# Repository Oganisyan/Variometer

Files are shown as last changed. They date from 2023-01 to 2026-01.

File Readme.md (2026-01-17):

# Paragliding Variometer on Basis of BikePilot2+ or Falk Tiger evo/geo/pro.
| AutoRunCE XCSoar | AutoRunCE Main Dialog | AutoRunCE Vario Settings |
|---|---|---|
|[](https://youtube.com/shorts/pAdE8dn8gpc)|[](https://youtube.com/shorts/2ggxs6w_VHQ)|[](https://youtube.com/shorts/l3dTKEIAxWs)|
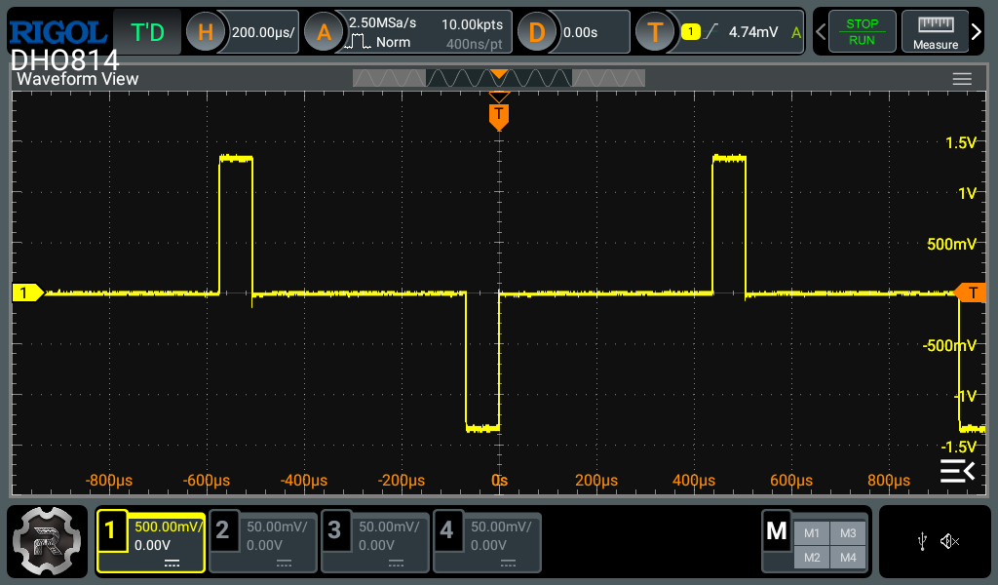
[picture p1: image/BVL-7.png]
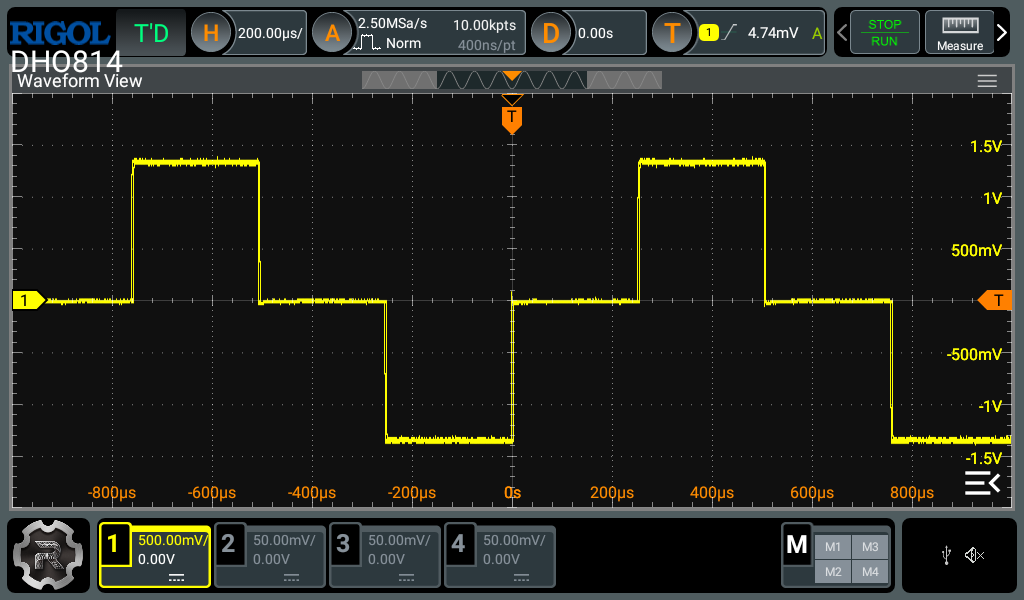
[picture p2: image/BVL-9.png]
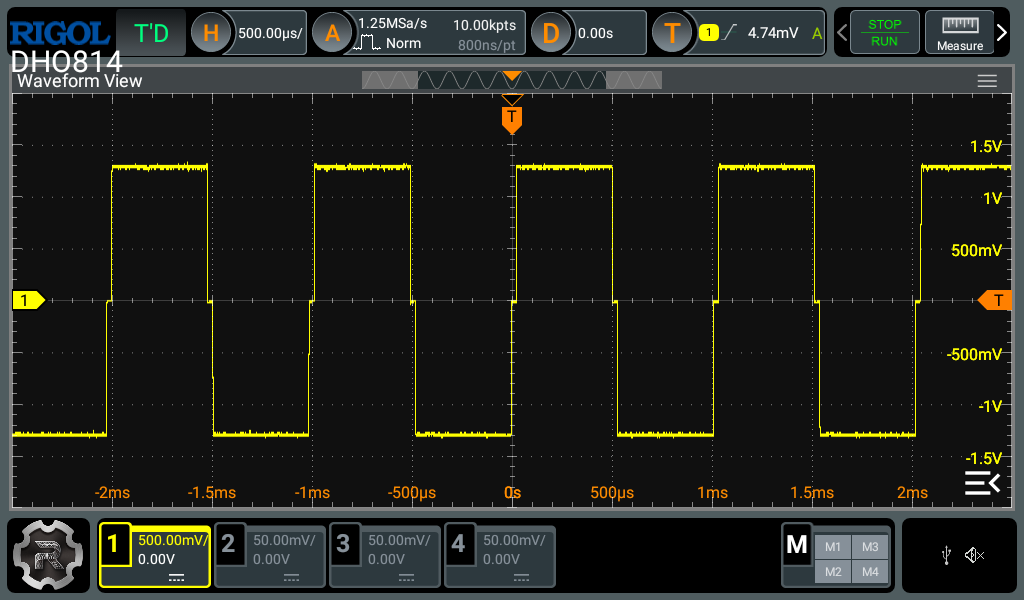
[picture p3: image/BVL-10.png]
| $BVL 7*|$BVL 9*|$BVL 10*|

## Build Step 1
build serial variometer and upload firmware
| | |
|---|---|
|Build informations |[./ATMega328P-AU/Readme.md](./ATMega328P-AU/Readme.md) |
|Firmware with bootloader |[./Firmware/SerialVariometer.with_bootloader.hex](./Firmware/SerialVariometer.with_bootloader.hex) |
|Firmware without bootloader  |[./Firmware/SerialVariometer.hex](./Firmware/SerialVariometer.hex) |

## Build Step 2
Open the BikePilot2+ and Install Serilal Variometer.
|                 Assembly                     |
|----------------------------------------------|
|                 |

## Build Step 3
Prepare the USB stick and insert the device (BikePilot2+).
|                                                                                        |
|----------------------------------------------------------------------------------------|
|copy [./Firmware/AutoRunCE.exe](./Firmware/AutoRunCE.exe) into root folder from USB stick |
|copy [./Firmware/AutoRunCE.ini](./Firmware/AutoRunCE.ini) into root folder from USB stick |
|copy [./Firmware/XCSoar.exe](./Firmware/XCSoar.exe) or www.xcsoar.org/Downloads into XCSoarData folder from USB stick |

| | |
|---|---|
|First  NMEA port / GPS signal|XCSoar gets GPS signal from COM0: (Bikepilot internal GPS).|
|Second NMEA port / pressure |AutoRunCE blocks serial variometer port (COM4 ) and forwards it to XCSoar via UDP broadcast on port 8882, BlueFly protocol should be used here.|

## done

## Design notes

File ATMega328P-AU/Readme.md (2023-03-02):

# Serial commands for variometer.
| Descripton | command line | value type |  value min | value max |
|---|---|---|---|---|
| set volume level | $BVL VALUE* |  INTEGER | 0 - OFF | 9 - max value |
| set lift threshold | $BUP VALUE* |  INTEGER | 0 - 0 m/s | 400 - 4 m/s |
| set sink threshold | $BDW VALUE* |  INTEGER | 0 - 0 m/s | 400 - 4 m/s |
| lift/sink simulation  | $SIM VALUE* |  INTEGER | -800 - 8m/s sink | 800 - 8m/s lift |
| reboot | $RST VALUE* |  INTEGER | 0 - reboot now | x - reboot in x seconds| 

# First step create serial variometer.

Before ATMega328P chip is soldered it is very important to upload bootloader for 8MHz internal crystal through SPI interface.
The firmware can be uploaded with the serial interface, but not the bootloader.

| | |
|---|---|
|Serial Vario for BikePilot2  | |
|Public folder for Production |https://aisler.net/p/OTGDHGCV |
|Fritzing Project & PCB files |[./pcb](./pcb) |
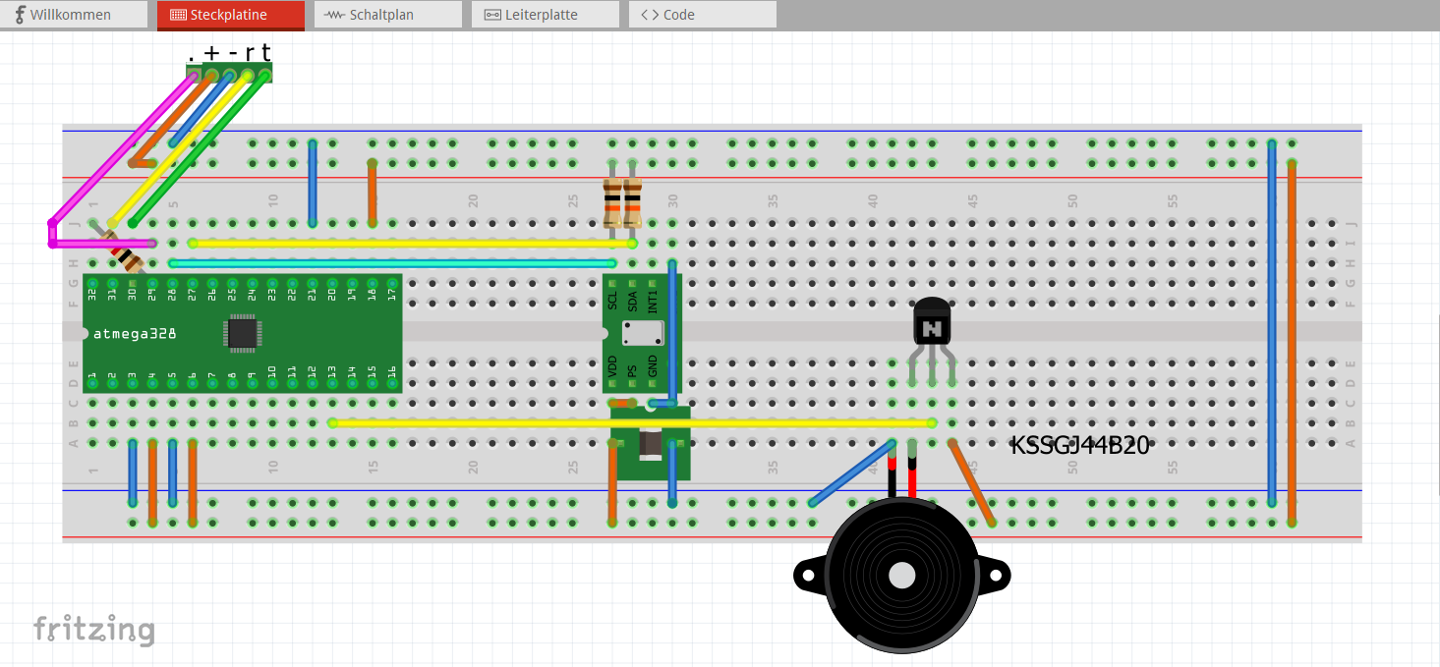
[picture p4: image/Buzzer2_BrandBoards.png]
|Breakout boards | |
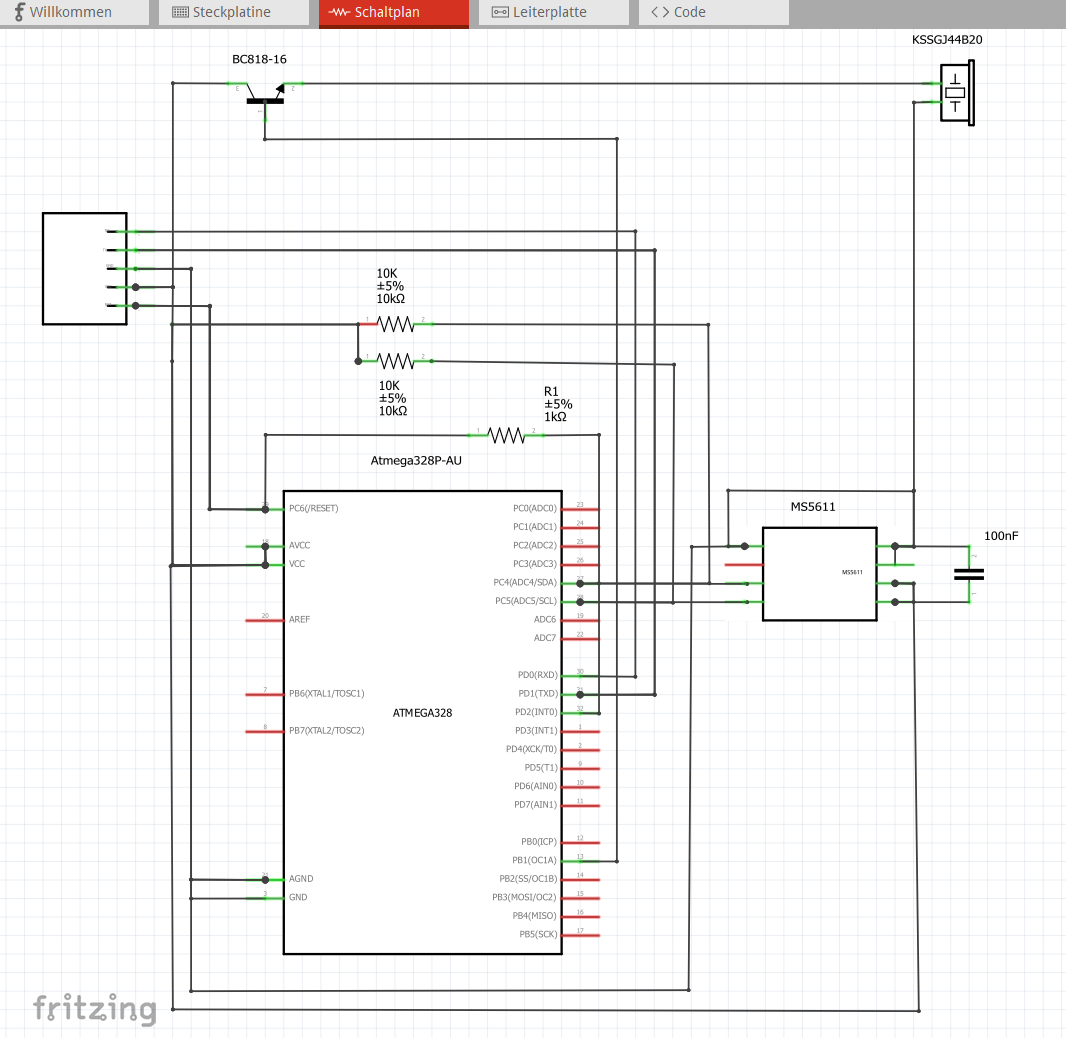
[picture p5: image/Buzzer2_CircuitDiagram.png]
|Circuit diagram ||

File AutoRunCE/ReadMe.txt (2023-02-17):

================================================================================
    MICROSOFT FOUNDATION CLASS-BIBLIOTHEK: AutoRunCE-Projektübersicht
===============================================================================

Der Anwendungs-Assistent hat diese AutoRunCE-Anwendung für Sie 
erstellt. Diese Anwendung zeigt nicht nur die Grundlagen der Verwendung von 
Microsoft Foundation Classes, sondern dient auch als Ausgangspunkt für das 
Schreiben Ihrer Anwendung.

Diese Datei enthält eine Zusammenfassung dessen, was Sie in jeder der Dateien
finden, aus denen Ihre AutoRunCE–Anwendung besteht.

AutoRunCE.vcproj
    Dies ist die Hauptprojektdatei für VC++-Projekte, die mithilfe eines 
    Anwendungs-Assistenten erstellt werden. 
    Sie enthält Informationen über die Version von Visual C++, in der die Datei 
    erzeugt wurde, sowie Informationen über die Plattformen, Konfigurationen und 
    Projektfunktionen, die mit dem Anwendungs-Assistenten ausgewählt wurden.

AutoRunCE.h
    Dies ist die Hauptheaderdatei für die Anwendung. Sie enthält weitere
    projektspezifische Header und deklariert die CAutoRunCEApp-
    Anwendungsklasse.

AutoRunCE.cpp
    Dies ist die Hauptquelldatei der Anwendung, die die CAutoRunCEApp-
    Anwendungsklasse enthält.

AutoRunCE.rc
    Dies ist die Hauptressourcendatei des Projekts, die alle Microsoft Windows-
    Ressourcen auflistet, die das Projekt verwendet. Sie enthält die Symbole, 
    Bitmaps und Cursor, die im Unterverzeichnis "RES" gespeichert werden. Diese 
    Datei kann direkt in Microsoft Visual C++ bearbeitet werden. Ihre 
    Projektressourcen befinden sich in 1031.
    Wenn die RC-Datei beibehalten wird, werden die Definitionen im 
    Datenabschnitt als Hexadezimalversion des numerischen Wertes, für den sie 
    definiert sind, gespeichert, und nicht als der angezeigte Name der 
    Definition.

res\AutoRunCE.rc2
    Diese Datei enthält Ressourcen, die nicht von Microsoft Visual C++
    bearbeitet werden. Sie sollten alle Ressourcen, die nicht mit dem
    Ressourcen-Editor bearbeitet werden können, in dieser Datei platzieren.

res\AutoRunCE.ico
    Dies ist eine Symboldatei, die als Symbol der Anwendung verwendet wird. 
    Dieses Symbol ist in der Hauptressourcendatei enthalten.

/////////////////////////////////////////////////////////////////////////////

Der Anwendungs-Assistent erstellt eine Dialogfeldklasse:

AutoRunCEDlg.h, AutoRunCEDlg.cpp – das Dialogfeld
    Diese Dateien enthalten Ihre CAutoRunCEDlg–Klasse. Diese Klasse 
    bestimmt das Verhalten des Hauptdialogfelds Ihrer Anwendung. Die Vorlage des 
    Dialogfelds befindet sich in der Hauptressourcendatei, die in Microsoft 
    Visual C++ bearbeitet werden kann.

/////////////////////////////////////////////////////////////////////////////

Weitere Standarddateien:

StdAfx.h, StdAfx.cpp
    Diese Dateien werden verwendet, um eine vorkompilierte Headerdatei
    (PCH-Datei) mit dem Namen "AutoRunCE.pch2 und eine 
    vorkompilierte Typendatei mit dem Namen "StdAfx.obj" zu erstellen.

Resource.h
    Dies ist die Standardheaderdatei, die neue Ressourcen-IDs definiert.
    Microsoft Visual C++ liest und aktualisiert diese Datei.

/////////////////////////////////////////////////////////////////////////////

Weitere Hinweise:

Der Anwendungs-Assistent verwendet "TODO:, um auf Teile des Quellcodes
hinzuweisen, die Sie hinzufügen oder anpassen sollten.

Wenn Ihre Anwendung MFC in einer freigegebenen DLL verwendet und Ihre Anwendung
in einer anderen als der aktuellen Sprache des Betriebssystems vorliegt,
müssen Sie die entsprechenden lokalisierten Ressourcen "MFC90XXX.DLL" in Ihr
Anwendungsverzeichnis kopieren ("XXX" steht für die Sprachabkürzung. "MFC90DEU.DLL" enthält beispielsweise ins Deutsche übersetzte Ressourcen.) Wenn Sie dies nicht tun, bleiben einige der Benutzeroberflächenelemente Ihrer Anwendung in der Sprache des Betriebssystems.

/////////////////////////////////////////////////////////////////////////////

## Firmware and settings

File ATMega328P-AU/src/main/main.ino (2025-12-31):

#include <Arduino.h>
#include <Wire.h>
#include "Tone.h"
#include "Reader.h"
#include "Config.h"
#include <avr/wdt.h>

#include "MS5611.h"

// PIN I2C_SCL              A4 // PC4
// PIN I2C_SDA              A5 // PC5
#define BEEP_PIN            A2 // PC2
//#define RX_PIN            10 // PB2 
//#define TX_PIN            9  // PB1
#define RESET_PIN           2

#define EEPROM_ADDRESE_VALUE  0



float   toneFreqLowpass, pressure, lowpassFast, lowpassSlow, upBarrier, upMax, dwBarrier, dwMax, sim = 0.F, P1, P2, P3, P4;

int16_t ddsAcc;

MS5611 ms5611(Wire);
Tone   myTone;
Reader reader(Serial);
Config config;



void sensitivity (int sensi) {
  sensi =  constrain(sensi, SEN_MIN, SEN_MAX);
  P1 = (5.F+ sensi)/50;
  P2 = P1 / 2;
  P3 = 500.F * P1;
  P4 = P3 * P1;
  config.setSensi(sensi);
}

void printBr() {
  Serial.print("UpBr: ");
  Serial.print(upBarrier);
  Serial.print(" UpMax: ");
  Serial.print(upMax);
  Serial.print(" DwBr: ");
  Serial.print(dwBarrier);
  Serial.print(" DwMax ");
  Serial.println(dwMax);
}

// up barrier m/s*100
void setUpBarrier(int up_100) {
  up_100 = constrain(up_100, UP_MIN, UP_MAX);
  upBarrier=max(25.F, 1.6F*up_100);
  upMax=upBarrier+600.F;
  config.setUp100(up_100);
}
// down barrier m/s*100
void setDownBarrier(int down_100) {
  down_100 = constrain(down_100, DW_MIN, DW_MAX);
  dwBarrier=min(-25.F, -1.6F*down_100);
  dwMax=dwBarrier-200.F;
  config.setDown100(down_100);
}

void setVolume(int volume) {
  volume = constrain(volume, VOL_MIN, VOL_MAX);
  myTone.setVolume(volume);
  config.setVolume(volume);
  myTone.beep(NOTONEAC);
}

float calibrate(float freq)
{
  freq = constrain(freq, dwMax, upMax);
  freq -= constrain(freq, dwBarrier, upBarrier);
  return  freq;
}



void hardwareReset(uint32_t milis) {
  Serial.end();
  pinMode(0, OUTPUT);
  pinMode(1, OUTPUT);
  pinMode(RESET_PIN, OUTPUT);
  digitalWrite(0,LOW);
  digitalWrite(1,LOW);
  delay(milis);
  digitalWrite(RESET_PIN,LOW);
}

void sendPressure(uint32_t p) {
  static char buffer[32];
  int len = sprintf(buffer, "PRS %lX\n", p);
  Serial.write(buffer, len);
}

void setup() {
  digitalWrite(RESET_PIN,HIGH);
  Serial.begin(57600);
  ms5611.begin();
  sensitivity(config.getSensi());
  while(!ms5611.isReady()) {
    ms5611.loop();
    Serial.print(".");
    delay(1000);
  }

  pressure = ((double)ms5611.getPressure());
  lowpassFast = lowpassSlow = pressure;
  toneFreqLowpass = 0;
  setVolume(config.getVolume());
  setUpBarrier(config.getUp100());
  setDownBarrier(config.getDown100());
}

void loop() {  // run over and over
  static unsigned long delayUntilMillis= 0L;
  reader.loop();
  if(reader.hasLine()) {
    String cmd = reader.getLine();
    if(cmd.startsWith("$BVL") && cmd.indexOf('*') > 0 ) {
      int startIndex = 4;
      while(!isgraph(cmd[startIndex])) startIndex++;
      int value = cmd.substring(startIndex, cmd.indexOf('*')).toInt();
      setVolume(value);
    } else if(cmd.startsWith("$BUP") && cmd.indexOf('*') > 0 ) {
      int startIndex = 4;
      while(!isgraph(cmd[startIndex])) startIndex++;
      int value = cmd.substring(startIndex, cmd.indexOf('*')).toInt();
      setUpBarrier(value);
    } else if(cmd.startsWith("$BDW") && cmd.indexOf('*') > 0 ) {
      int startIndex = 4;
      while(!isgraph(cmd[startIndex])) startIndex++;
      int value = cmd.substring(startIndex, cmd.indexOf('*')).toInt();
      setDownBarrier(value);
    } else if(cmd.startsWith("$RST") && cmd.indexOf('*') > 0 ) {
      int startIndex = 4;
      while(!isgraph(cmd[startIndex])) startIndex++;
      int value = cmd.substring(startIndex, cmd.indexOf('*')).toInt();
      hardwareReset(value*1000);
    } else if(cmd.startsWith("$UPD") && cmd.indexOf('*') > 0 ) {
      config.save();
    } else if(cmd.startsWith("$SEN") && cmd.indexOf('*') > 0 ) {
      int startIndex = 4;
      while(!isgraph(cmd[startIndex])) startIndex++;
      int value = cmd.substring(startIndex, cmd.indexOf('*')).toInt();
      sensitivity(value);
    } else if(cmd.startsWith("$SIM") && cmd.indexOf('*') > 0 ) {
      int startIndex = 4;
      while(!isgraph(cmd[startIndex])) startIndex++;
      sim = cmd.substring(startIndex, cmd.indexOf('*')).toInt()*1.6F;
    } else if(cmd.startsWith("$?") || cmd.indexOf('*') > 0 ) {
      delayUntilMillis = millis() + 10000L;;
      Serial.flush();
      char buffer[16];
      sprintf(buffer, "$BVL %d*", config.getVolume());
      Serial.println(buffer);
      sprintf(buffer, "$BUP %d*", config.getUp100());
      Serial.println(buffer);
      sprintf(buffer, "$BDW %d*", config.getDown100());
      Serial.println(buffer);
      sprintf(buffer, "$SEN %d*", config.getSensi());
      Serial.println(buffer);
      Serial.println();
      Serial.println("Information:");
      Serial.println("\t$BVL value*   - set beep value (0 <-> 10)");
      Serial.println("\t$BUP barrier* - set up barrier (0=0,25m/s <-> 400=7m/s)");
      Serial.println("\t$BDW barrier* - set down barrier (0=0,25m/s <-> 400=7m/s)");
      Serial.println("\t$SEN sensy*   - set sensitivity (0 <-> 5)");
      Serial.println("\t$UPD *        - save config to flash");
      Serial.println("\t$SIM sim*     - simulate set down barrier (-600 <-> 600)");
      Serial.println("\t$? *          - print this");
      Serial.println();
    }
  }
  
  ms5611.loop();

  
  if(ms5611.isReady()) {
    uint32_t p = ms5611.getPressure();
    pressure = (double) p;
        
    lowpassFast = lowpassFast + (pressure - lowpassFast) * P1;
    lowpassSlow = lowpassSlow + (pressure - lowpassSlow) * P2;
    float toneFreq = (lowpassSlow - lowpassFast) * P3;
    toneFreqLowpass = toneFreqLowpass + (toneFreq - toneFreqLowpass) * P1;
    toneFreq = calibrate(toneFreqLowpass + sim);
    
    ddsAcc += toneFreq * 10 + 1000;

    if ((toneFreq > P4 && ddsAcc > 0) || (toneFreq < -P4))  {
      toneFreq += toneFreq > 0 ? 550 : 450;
      myTone.beep(toneFreq);
    } else {
      myTone.beep(0);
    }
    if(delayUntilMillis < millis())
      sendPressure(p);
  }
}

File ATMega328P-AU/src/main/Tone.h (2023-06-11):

#ifndef _TONE_H_
#define _TONE_H_
#include <Arduino.h>

#define NOTONEAC 0

#if defined (__AVR_ATmega32U4__) || defined(__AVR_ATmega640__) || defined(__AVR_ATmega1280__) || defined(__AVR_ATmega1281__) || defined(__AVR_ATmega2560__) || defined(__AVR_ATmega2561__) || defined(__AVR_AT90USB646__) || defined(__AVR_AT90USB1286__)
  #define PWMT1AMASK DDB5
  #define PWMT1BMASK DDB6
  #define PWMT1DREG DDRB
  #define PWMT1PORT PORTB
#elif defined(__AVR_ATmega1284P__) || defined(__AVR_ATmega644__) || defined(__AVR_ATmega644P__)
  #define PWMT1AMASK DDD4
  #define PWMT1BMASK DDD5
  #define PWMT1DREG DDRD
  #define PWMT1PORT PORTD
#else
  #define PWMT1AMASK DDB1
  #define PWMT1BMASK DDB2
  #define PWMT1DREG DDRB
  #define PWMT1PORT PORTB
#endif



class Tone {
  
  int8_t volume_;
  uint32_t frequency;

  public:
    Tone(int8_t volume = NOTONEAC);
    void beep(uint32_t frequency = NOTONEAC);
    void setVolume(int8_t volume);
    int8_t getVolume();

};


#endif //_TONE_H_

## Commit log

2022-12-18 Add PCB to Project.
    [Buzzer2.fzz]
2022-12-20 Bugfix for pressure filter.
    [Tone.h, main.ino]
2023-01-15 First public PCB.
    [Buzzer2.fzz]
2023-01-15 Add image folder
    [Buzzer2.fzz]
2023-01-25 Add HardwareReset to command interpreter. - > Allows firmware upload only with TX and RX wiring, without DTR wiring.
    [Buzzer2.fzz]
2023-01-29 Update BrandBoards.png and CircuitDiagram .ping
    [Buzzer2.fzz]
2023-02-17 Add Source Code for WinCE Runner.
    [Buzzer2.fzz]
2023-02-28 Add + and - buttons to simulation slider.
2023-03-03 Increase tone frequency by 100Hz.
2023-06-06 Send Data to socket in blocks.
2023-06-08 Bugfix for serial otput.
    [main.ino]
2024-09-03 Add $? command to print command information.
2025-12-28 Save Vario Settings in Flash.
    [Buzzer2.fzz]
2026-01-01 Remove sensor volume command settings
    Removed sensor volume command configurations from AutoRunCE.ini.
